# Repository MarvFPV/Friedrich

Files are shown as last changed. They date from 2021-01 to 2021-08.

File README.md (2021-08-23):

# Friedrich
50% 3D printed keyboard designed to be printable on regular sized 3d printers.

This place is designed to be 3d printed with a regular FDM printer, beware of that when ordering it from any other material. 

To make the case printable on regular machines, i had to cut it in half. To fuse those halves together you can either use super glue or melt them together by running a (clean) soldering iron tip through the seam (my preferred way). Make sure to re-tin your soldering iron afterwards tho as this process may damage your tip.

## Required components for handwires
* 52 MX style switches
* 2 2u MX platemount stabs
* 1 6.25u MX platemount stab
* 52 Diodes
* a Promicro
* one of ai03's [unified daughterboards](https://github.com/ai03-2725/Unified-Daughterboard)
* a few cables to wire up the matrix
* 4 m3x6mm screws
* 6 m3x8mm countersunk screws

I personally tend to remove the microUSB connector from the Promicro and solder it directly to a unified daughterboard, that's also why the Promicro cutout may not fit with the USB connector still on the PCB. (I should really write up some documentation on that ^^)

## PCB version
The PCB is not yet compatible with the switch plate in the repo, some cutting / melting away will have to be done to get it to fit with PCBmount stabs. Or just annoy me to add it ^^

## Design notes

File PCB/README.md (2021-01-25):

# Friedrich PCB

[][cc-by-nc-sa]

### Atmega32u4 based PCB for the Friedrich50 keyboard



---

[LCSC BOM](FriedrichPCB.csv)

[JLC CPL](FriedrichPCB_cpl_jlc.csv)

[JST connector for USB](https://www.digikey.de/product-detail/en/jst-sales-america-inc/SM04B-SRSS-TB-LF-SN/455-1804-1-ND/926875)

---




This work is licensed under a
[Creative Commons Attribution-NonCommercial-ShareAlike 4.0 International License][cc-by-nc-sa].

[][cc-by-nc-sa]

[cc-by-nc-sa]: http://creativecommons.org/licenses/by-nc-sa/4.0/
[cc-by-nc-sa-image]: https://licensebuttons.net/l/by-nc-sa/4.0/88x31.png
[cc-by-nc-sa-shield]: https://img.shields.io/badge/License-CC%20BY--NC--SA%204.0-lightgrey.svg

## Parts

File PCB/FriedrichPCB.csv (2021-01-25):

Comment | Designator | Footprint | LCSC
10uF | C1 | Capacitor_SMD:C_0805_2012Metric | C91245
0.1uF | C2,C3,C4,C5 | Capacitor_SMD:C_0805_2012Metric | C49678
1uF | C7 | Capacitor_SMD:C_0805_2012Metric | C28323
22pF | C8,C9 | Capacitor_SMD:C_0805_2012Metric | C1804
D_Small | D1,D2,D3,D4,D5,D6,D7,D8,D9,D10,D11,D12,D13,D14,D15,D16,D17,D18,D19,D20,D21,D22,D23,D24,D25,D27,D28,D29,D30,D31,D32,D33,D34,D35,D36,D38,D40,D41,D42,D43,D44,D45,D46,D47,D48,D49,D51,D53,D54,D58,D62,D63 | Diode_SMD:D_SOD-123 | C81598
Polyfuse_Small | F1 | Fuse:Fuse_1206_3216Metric | C163133
MX-NoLED | MX1,MX2,MX3,MX4,MX5,MX6,MX7,MX8,MX9,MX10,MX11,MX12,MX13,MX15,MX16,MX17,MX18,MX19,MX20,MX21,MX22,MX23,MX24,MX28,MX29,MX30,MX31,MX32,MX33,MX34,MX35,MX36,MX41,MX42,MX43,MX44,MX45,MX46,MX47,MX48,MX49,MX53,MX63 | MX_Only:MXOnly-1U-NoLED
MX-NoLED | MX14,MX25 | MX_Only:MXOnly-1.5U-NoLED
MX-NoLED | MX27,MX51 | MX_Only:MXOnly-1.75U-NoLED
MX-NoLED | MX38 | MX_Only:MXOnly-2.25U-NoLED
MX-NoLED | MX40 | MX_Only:MXOnly-2.25U-ReversedStabilizers-NoLED
MX-NoLED | MX54,MX62 | MX_Only:MXOnly-1.25U-NoLED
MX-NoLED | MX58 | MX_Only:MXOnly-6.25U-ReversedStabilizers-NoLED
22 | R1,R2 | Resistor_SMD:R_0805_2012Metric | C17561
10k | R3,R5 | Resistor_SMD:R_0805_2012Metric | C17414
SW_Push | RESET | Button_Switch_SMD:SW_SPST_TL3342 | C318884
ATmega32U4-AU | U1 | Package_QFP:TQFP-44_10x10mm_P0.8mm | C44854
SRV05-4 | U2 | Package_TO_SOT_SMD:SOT-23-6 | C85364
Conn_01x04 | USB1 | Connector_JST:JST_SH_SM04B-SRSS-TB_1x04-1MP_P1.00mm_Horizontal
Crystal_GND24_Small | X1 | Crystal:Crystal_SMD_3225-4Pin_3.2x2.5mm | C13738

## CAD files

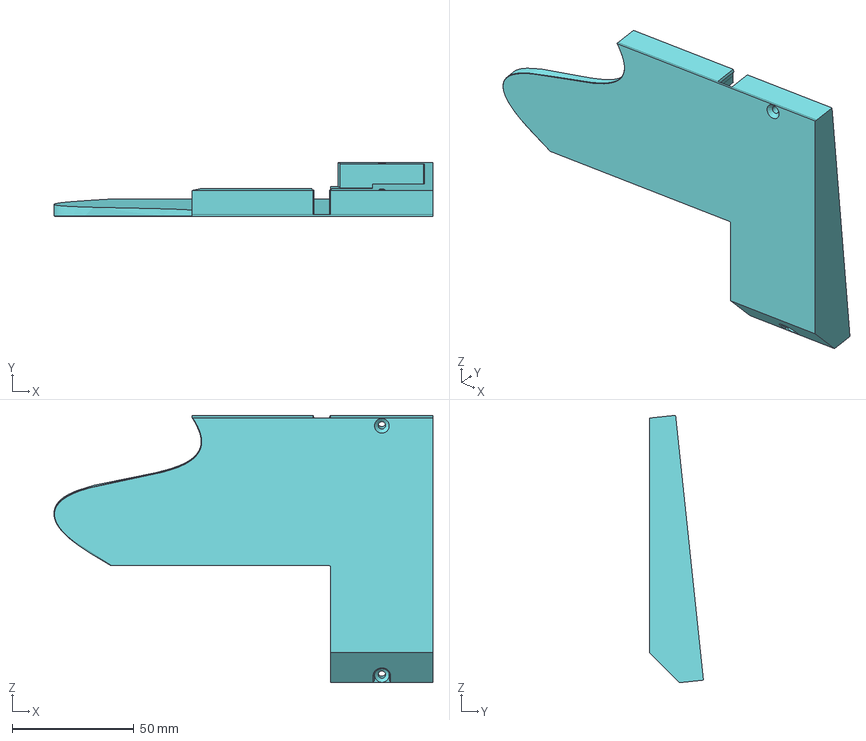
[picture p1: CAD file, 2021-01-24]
STEP/BottomRight.step
155.3 x 22.1 x 109.6 mm

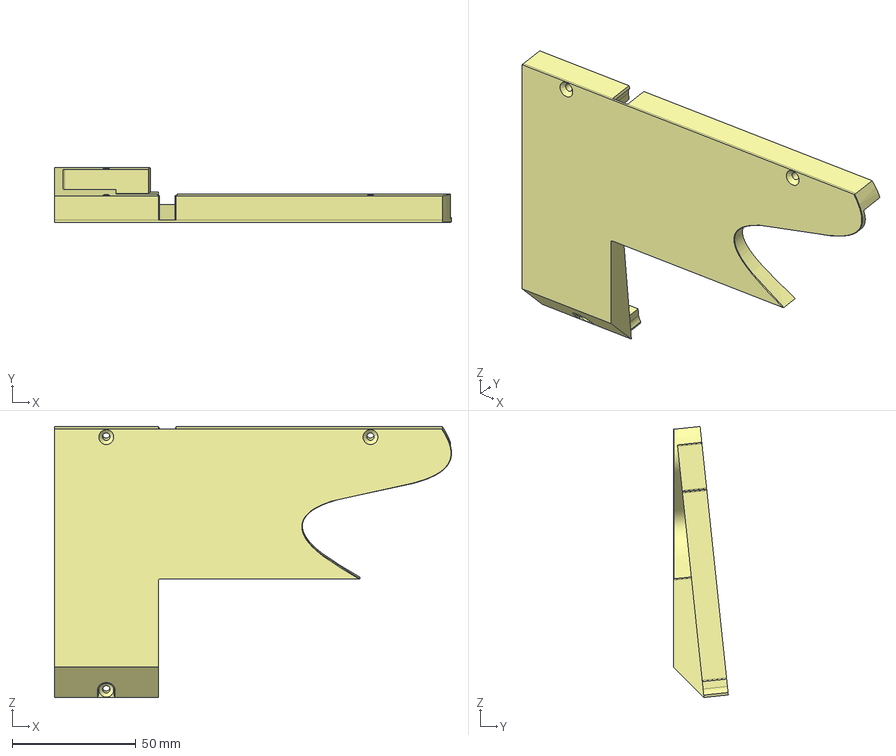
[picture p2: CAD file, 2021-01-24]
STEP/BottomLeft.step
160.5 x 22.1 x 109.6 mm

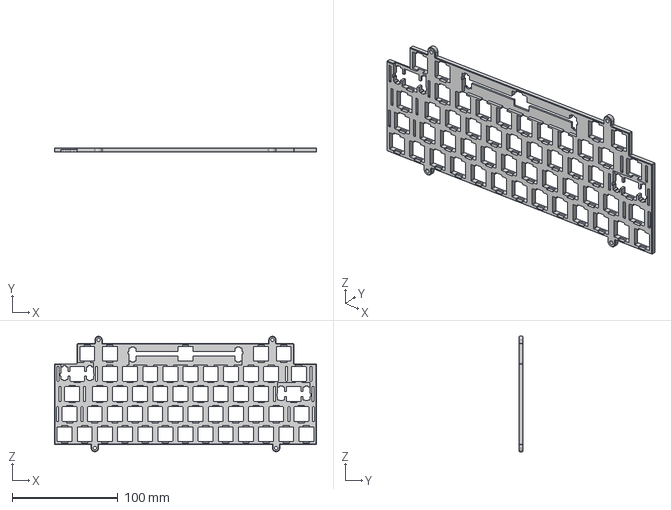
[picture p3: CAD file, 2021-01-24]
STEP/Plate.step
247.7 x 4.00 x 109.2 mm

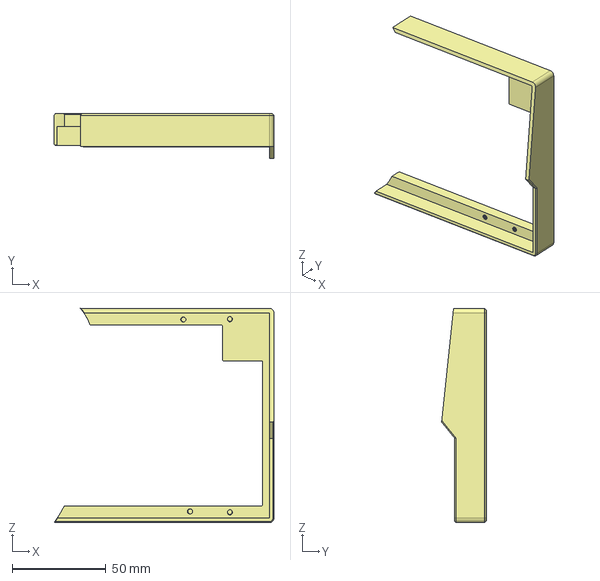
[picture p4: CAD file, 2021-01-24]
STEP/TopRight.step
117.2 x 23.9 x 114.2 mm

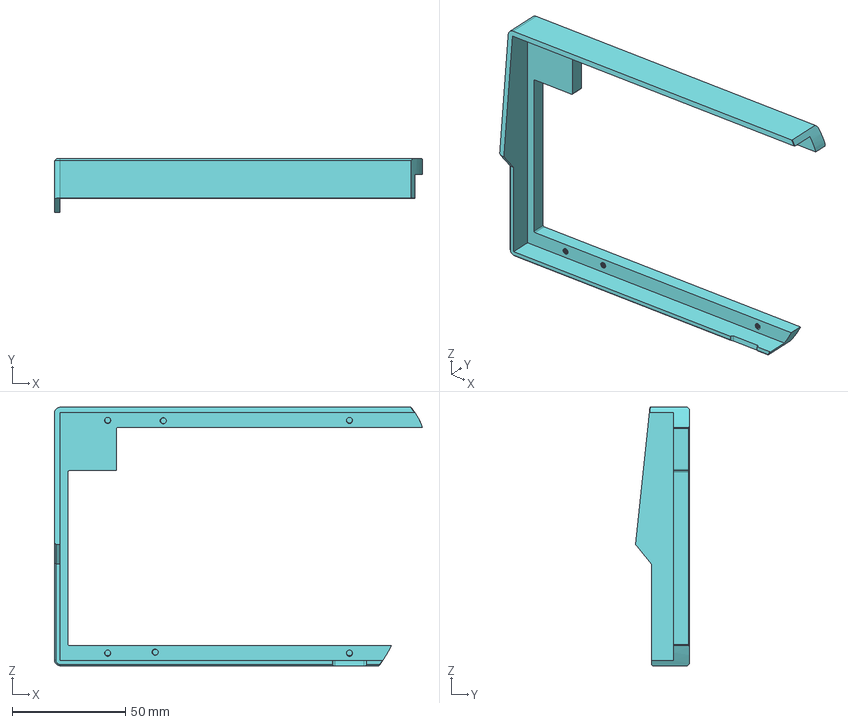
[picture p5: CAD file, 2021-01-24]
STEP/TopLeft.step
162.6 x 23.9 x 114.3 mm

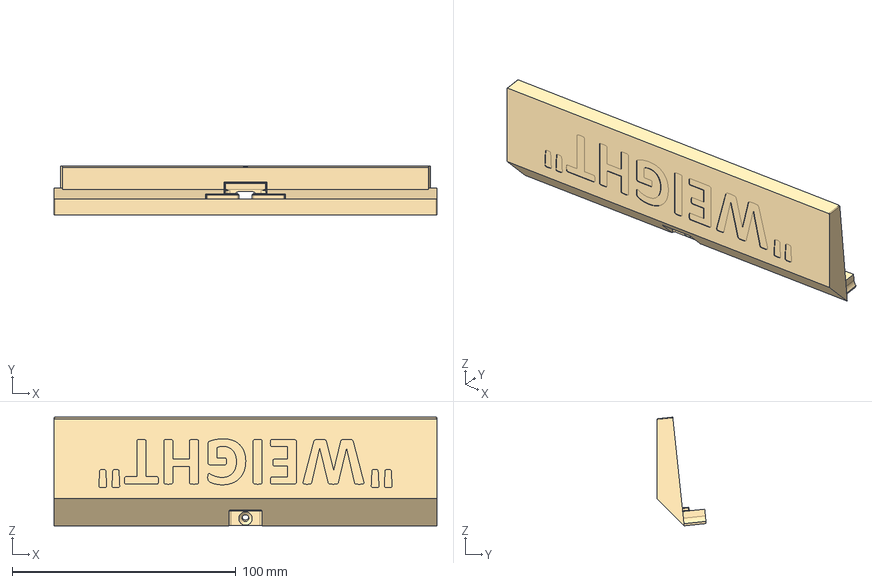
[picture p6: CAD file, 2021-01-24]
STEP/Weight.step
171.1 x 22.1 x 48.6 mm

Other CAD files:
STL/BottomLeft.stl
STL/BottomRight.stl
STL/Plate.stl
STL/TopLeft.stl
STL/TopRight.stl
STL/Weight.stl

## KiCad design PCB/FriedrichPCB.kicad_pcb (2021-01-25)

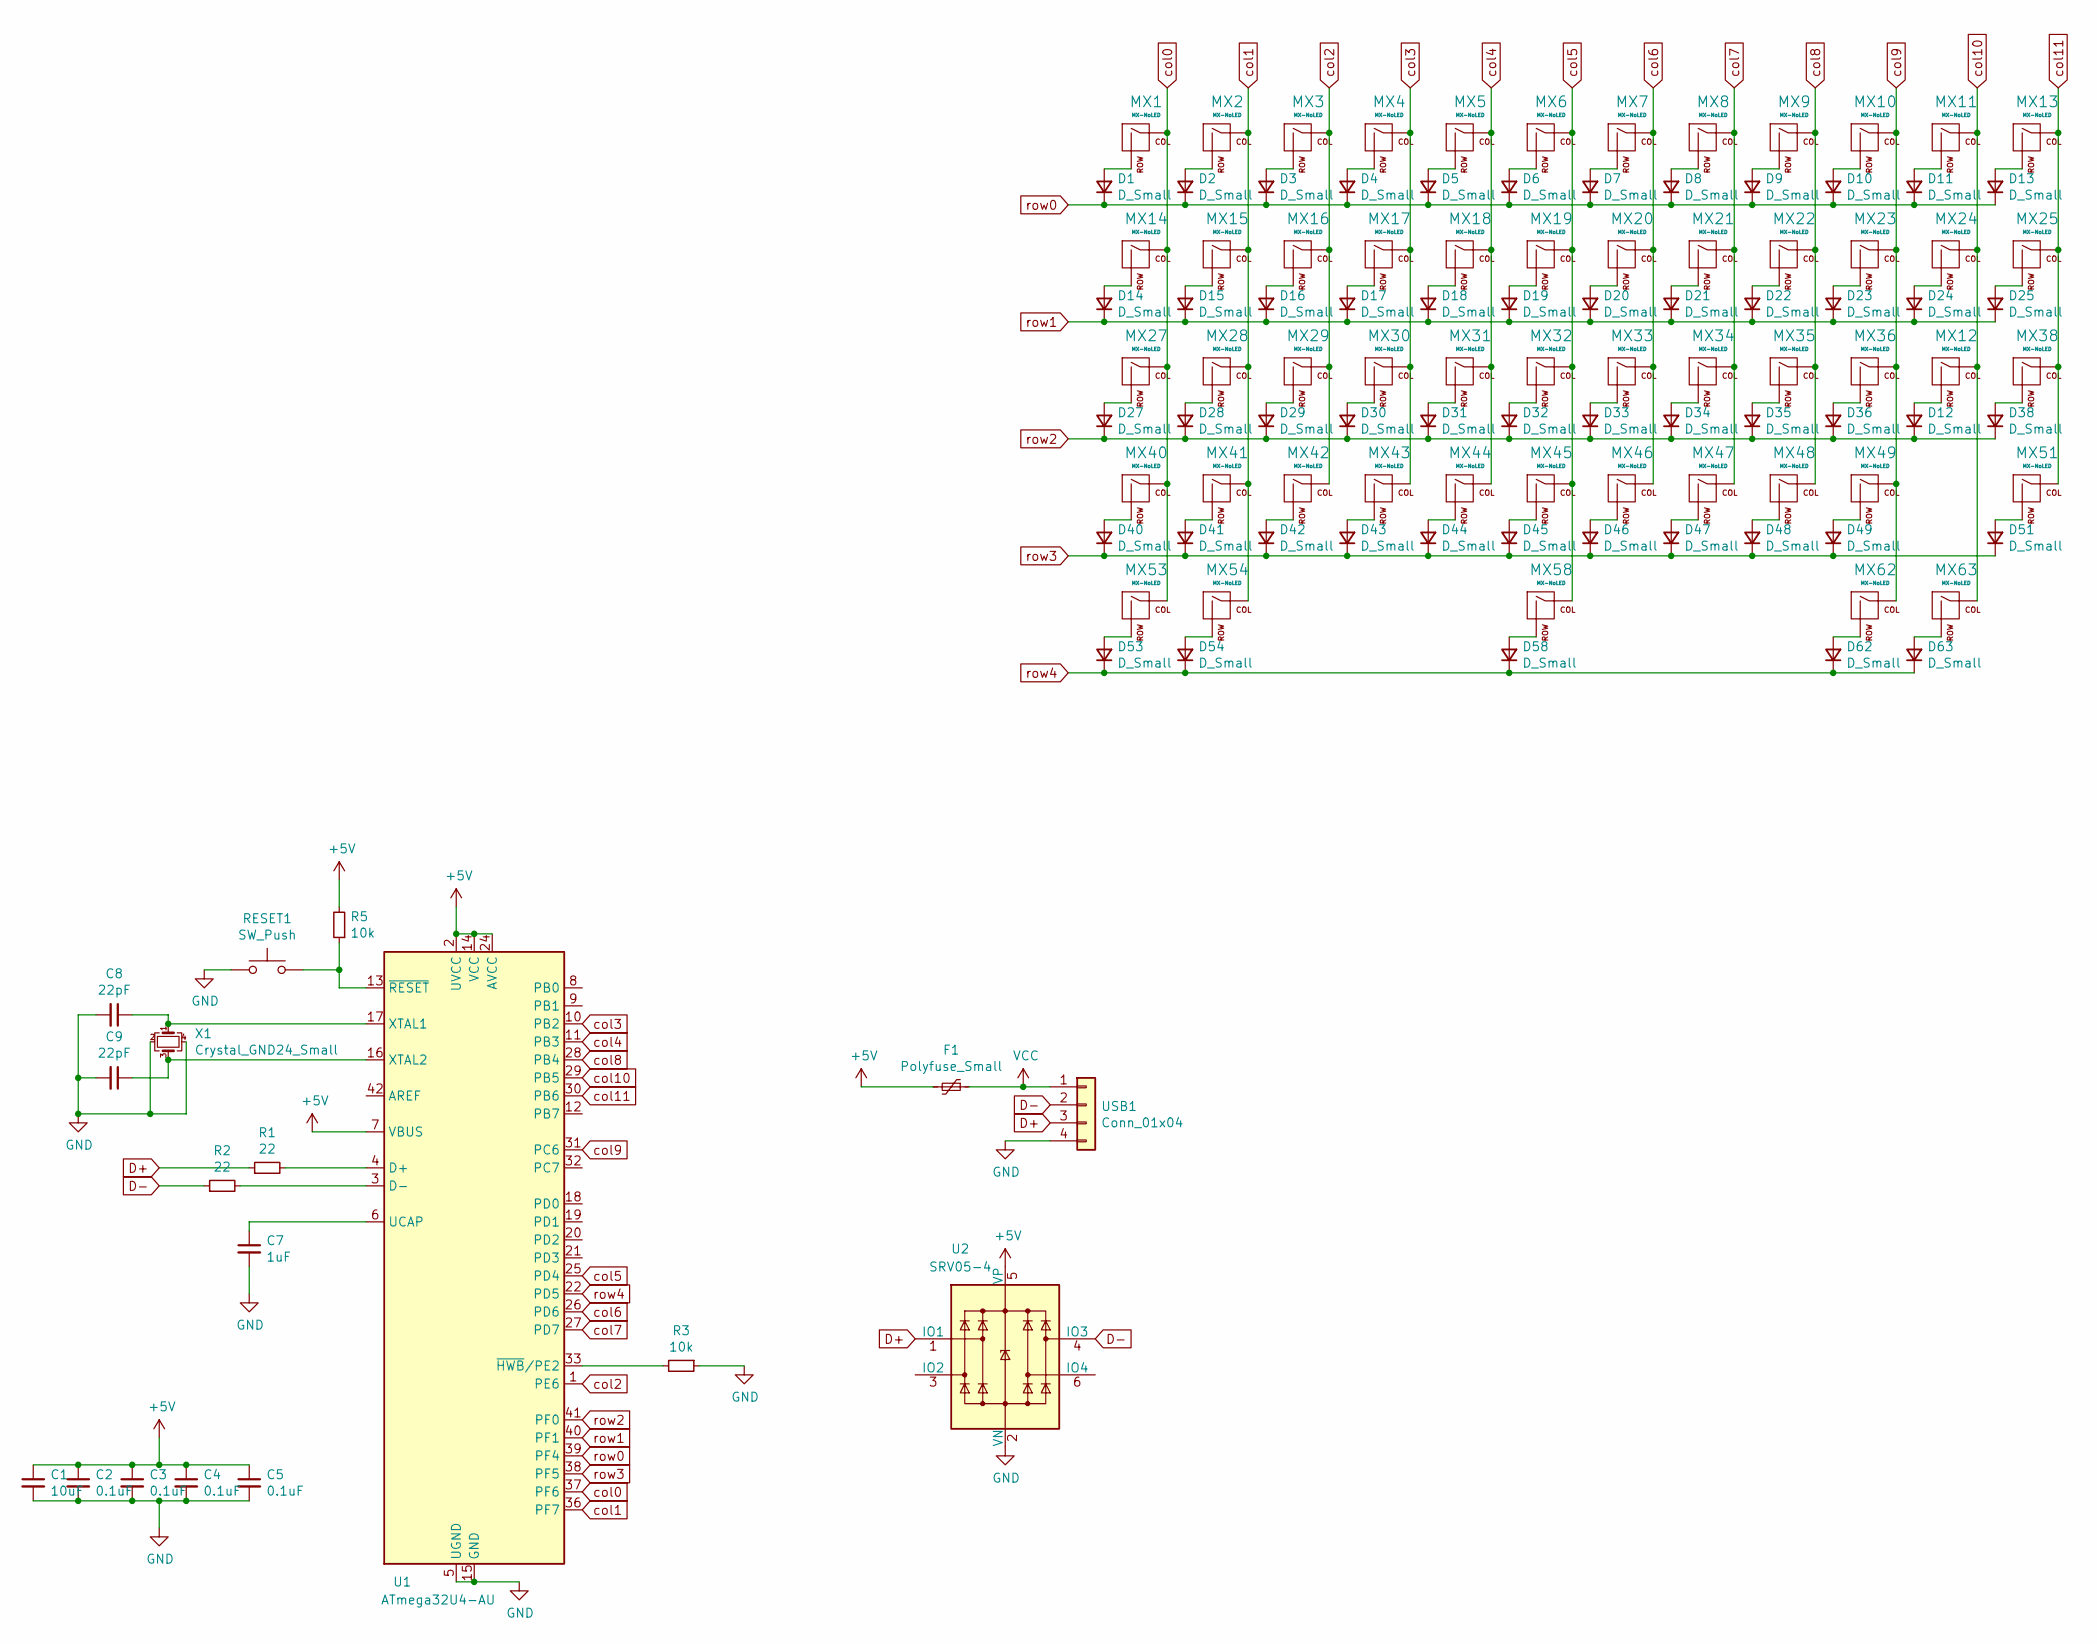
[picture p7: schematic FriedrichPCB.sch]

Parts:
C1: 10uF; C_0805_2012Metric; LCSC C91245
C2, C3, C4, C5: 0.1uF; C_0805_2012Metric; LCSC C49678
C7: 1uF; C_0805_2012Metric; LCSC C28323
C8, C9: 22pF; C_0805_2012Metric; LCSC C1804
D1, D2, D3, D4, D5, D6, D7, D8, D9, D10, D11, D12, D13, D14, D15, D16, D17, D18, D19, D20, D21, D22, D23, D24, D25, D27, D28, D29, D30, D31, D32, D33, D34, D35, D36, D38, D40, D41, D42, D43, D44, D45, D46, D47, D48, D49, D51, D53, D54, D58, D62, D63: D_Small; D_SOD-123; LCSC C81598
F1: Polyfuse_Small; Fuse_1206_3216Metric; LCSC C163133
MX1, MX2, MX3, MX4, MX5, MX6, MX7, MX8, MX9, MX10, MX11, MX12, MX13, MX15, MX16, MX17, MX18, MX19, MX20, MX21, MX22, MX23, MX24, MX28, MX29, MX30, MX31, MX32, MX33, MX34, MX35, MX36, MX41, MX42, MX43, MX44, MX45, MX46, MX47, MX48, MX49, MX53, MX63: MX-NoLED; MXOnly-1U-NoLED
MX14, MX25: MX-NoLED; MXOnly-1.5U-NoLED
MX27, MX51: MX-NoLED; MXOnly-1.75U-NoLED
MX38: MX-NoLED; MXOnly-2.25U-NoLED
MX40: MX-NoLED; MXOnly-2.25U-ReversedStabilizers-NoLED
MX54, MX62: MX-NoLED; MXOnly-1.25U-NoLED
MX58: MX-NoLED; MXOnly-6.25U-ReversedStabilizers-NoLED
R1, R2: 22; R_0805_2012Metric; LCSC C17561
R3, R5: 10k; R_0805_2012Metric; LCSC C17414
RESET1: SW_Push; SW_SPST_TL3342; LCSC C318884
U1: ATmega32U4-AU; TQFP-44_10x10mm_P0.8mm; LCSC C44854
U2: SRV05-4; SOT-23-6; LCSC C85364
USB1: Conn_01x04; JST_SH_SM04B-SRSS-TB_1x04-1MP_P1.00mm_Horizontal
X1: Crystal_GND24_Small; Crystal_SMD_3225-4Pin_3.2x2.5mm; LCSC C13738

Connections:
+5V: C1.1, C2.1, C3.1, C4.1, C5.1, F1.2, R5.2, U1.2 (UVCC), U1.7 (VBUS), U1.14 (VCC), U1.24 (AVCC), U1.34 (VCC), U1.44 (AVCC), U2.5 (VP)
D+: R1.1, U2.1 (IO1), USB1.3
D-: R2.1, U2.4 (IO3), USB1.2
GND: C1.2, C2.2, C3.2, C4.2, C5.2, C7.2, C8.2, C9.2, R3.1, RESET1.1, U1.5 (UGND), U1.15 (GND), U1.23 (GND), U1.35 (GND), U1.43 (GND), U2.2 (VN), USB1.4, X1.2, X1.4; also elsewhere on the board
unnamed: C7.1, U1.6 (UCAP)
unnamed: C8.1, U1.17 (XTAL1), X1.1
unnamed: C9.1, U1.16 (XTAL2), X1.3
unnamed: D1.2 (A), MX1.2 (ROW)
unnamed: D2.2 (A), MX2.2 (ROW)
unnamed: D3.2 (A), MX3.2 (ROW)
unnamed: D4.2 (A), MX4.2 (ROW)
unnamed: D5.2 (A), MX5.2 (ROW)
unnamed: D6.2 (A), MX6.2 (ROW)
unnamed: D7.2 (A), MX7.2 (ROW)
unnamed: D8.2 (A), MX8.2 (ROW)
unnamed: D9.2 (A), MX9.2 (ROW)
unnamed: D10.2 (A), MX10.2 (ROW)
unnamed: D11.2 (A), MX11.2 (ROW)
unnamed: D12.2 (A), MX12.2 (ROW)
unnamed: D13.2 (A), MX13.2 (ROW)
unnamed: D14.2 (A), MX14.2 (ROW)
unnamed: D15.2 (A), MX15.2 (ROW)
unnamed: D16.2 (A), MX16.2 (ROW)
unnamed: D17.2 (A), MX17.2 (ROW)
unnamed: D18.2 (A), MX18.2 (ROW)
unnamed: D19.2 (A), MX19.2 (ROW)
unnamed: D20.2 (A), MX20.2 (ROW)
unnamed: D21.2 (A), MX21.2 (ROW)
unnamed: D22.2 (A), MX22.2 (ROW)
unnamed: D23.2 (A), MX23.2 (ROW)
unnamed: D24.2 (A), MX24.2 (ROW)
unnamed: D25.2 (A), MX25.2 (ROW)
unnamed: D27.2 (A), MX27.2 (ROW)
unnamed: D28.2 (A), MX28.2 (ROW)
unnamed: D29.2 (A), MX29.2 (ROW)
unnamed: D30.2 (A), MX30.2 (ROW)
unnamed: D31.2 (A), MX31.2 (ROW)
unnamed: D32.2 (A), MX32.2 (ROW)
unnamed: D33.2 (A), MX33.2 (ROW)
unnamed: D34.2 (A), MX34.2 (ROW)
unnamed: D35.2 (A), MX35.2 (ROW)
unnamed: D36.2 (A), MX36.2 (ROW)
unnamed: D38.2 (A), MX38.2 (ROW)
unnamed: D40.2 (A), MX40.2 (ROW)
unnamed: D41.2 (A), MX41.2 (ROW)
unnamed: D42.2 (A), MX42.2 (ROW)
unnamed: D43.2 (A), MX43.2 (ROW)
unnamed: D44.2 (A), MX44.2 (ROW)
unnamed: D45.2 (A), MX45.2 (ROW)
unnamed: D46.2 (A), MX46.2 (ROW)
unnamed: D47.2 (A), MX47.2 (ROW)
unnamed: D48.2 (A), MX48.2 (ROW)
unnamed: D49.2 (A), MX49.2 (ROW)
unnamed: D51.2 (A), MX51.2 (ROW)
unnamed: D53.2 (A), MX53.2 (ROW)
unnamed: D54.2 (A), MX54.2 (ROW)
unnamed: D58.2 (A), MX58.2 (ROW)
unnamed: D62.2 (A), MX62.2 (ROW)
unnamed: D63.2 (A), MX63.2 (ROW)
unnamed: R1.2, U1.4 (D+)
unnamed: R2.2, U1.3 (D-)
unnamed: R3.2, U1.33 (~HWB~/PE2)
unnamed 62: R5.1, RESET1.2, U1.13 (~RESET); also elsewhere on the board
VCC: F1.1, USB1.1
col0: MX1.1 (COL), MX14.1 (COL), MX27.1 (COL), MX40.1 (COL), MX53.1 (COL), U1.37 (PF6)
col1: MX2.1 (COL), MX15.1 (COL), MX28.1 (COL), MX41.1 (COL), MX54.1 (COL), U1.36 (PF7)
col2: MX3.1 (COL), MX16.1 (COL), MX29.1 (COL), MX42.1 (COL), U1.1 (PE6)
col3: MX4.1 (COL), MX17.1 (COL), MX30.1 (COL), MX43.1 (COL), U1.10 (PB2)
col4: MX5.1 (COL), MX18.1 (COL), MX31.1 (COL), MX44.1 (COL), U1.11 (PB3)
col5: MX6.1 (COL), MX19.1 (COL), MX32.1 (COL), MX45.1 (COL), MX58.1 (COL), U1.25 (PD4)
col6: MX7.1 (COL), MX20.1 (COL), MX33.1 (COL), MX46.1 (COL), U1.26 (PD6)
col7: MX8.1 (COL), MX21.1 (COL), MX34.1 (COL), MX47.1 (COL), U1.27 (PD7)
col8: MX9.1 (COL), MX22.1 (COL), MX35.1 (COL), MX48.1 (COL), U1.28 (PB4)
col9: MX10.1 (COL), MX23.1 (COL), MX36.1 (COL), MX49.1 (COL), MX62.1 (COL), U1.31 (PC6)
col10: MX11.1 (COL), MX12.1 (COL), MX24.1 (COL), MX63.1 (COL), U1.29 (PB5)
col11: MX13.1 (COL), MX25.1 (COL), MX38.1 (COL), MX51.1 (COL), U1.30 (PB6)
row0: D1.1 (K), D2.1 (K), D3.1 (K), D4.1 (K), D5.1 (K), D6.1 (K), D7.1 (K), D8.1 (K), D9.1 (K), D10.1 (K), D11.1 (K), D13.1 (K), U1.39 (PF4)
row1: D14.1 (K), D15.1 (K), D16.1 (K), D17.1 (K), D18.1 (K), D19.1 (K), D20.1 (K), D21.1 (K), D22.1 (K), D23.1 (K), D24.1 (K), D25.1 (K), U1.40 (PF1)
row2: D12.1 (K), D27.1 (K), D28.1 (K), D29.1 (K), D30.1 (K), D31.1 (K), D32.1 (K), D33.1 (K), D34.1 (K), D35.1 (K), D36.1 (K), D38.1 (K), U1.41 (PF0)
row3: D40.1 (K), D41.1 (K), D42.1 (K), D43.1 (K), D44.1 (K), D45.1 (K), D46.1 (K), D47.1 (K), D48.1 (K), D49.1 (K), D51.1 (K), U1.38 (PF5)
row4: D53.1 (K), D54.1 (K), D58.1 (K), D62.1 (K), D63.1 (K), U1.22 (PD5)

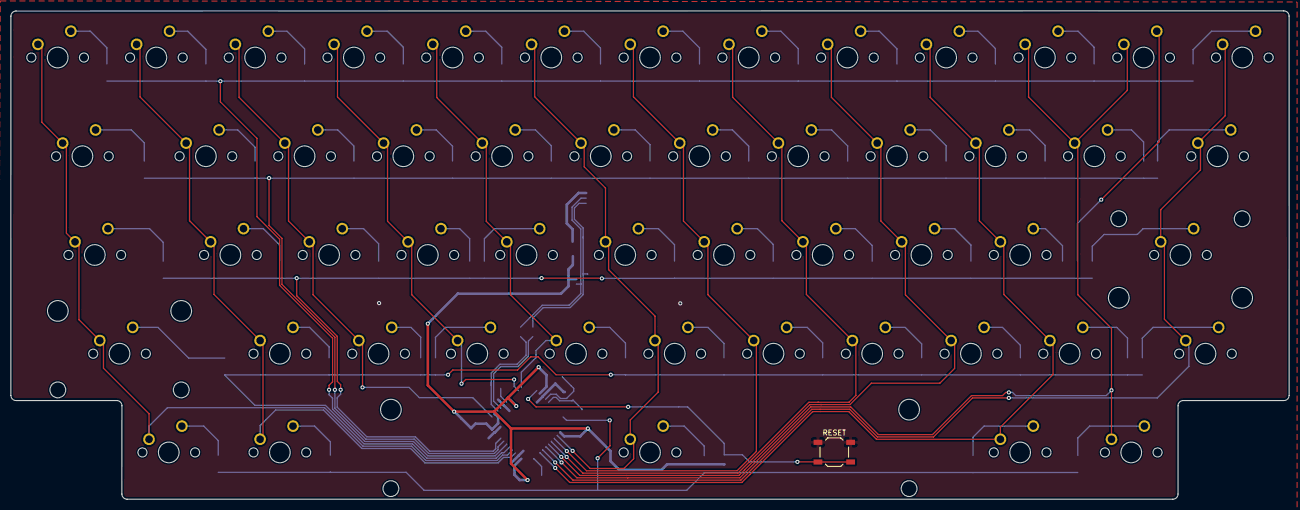
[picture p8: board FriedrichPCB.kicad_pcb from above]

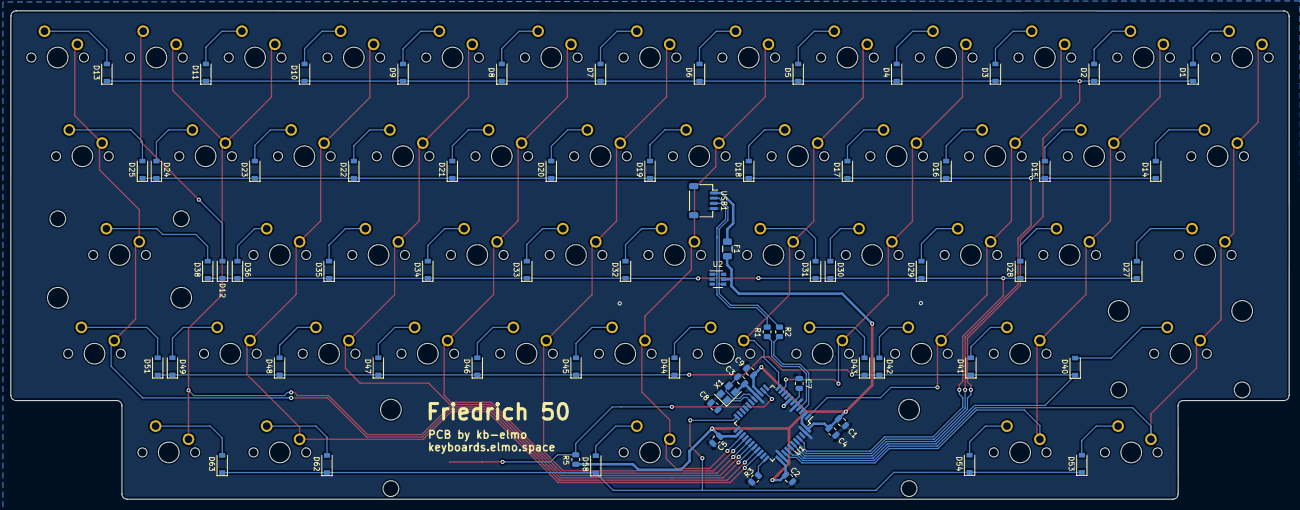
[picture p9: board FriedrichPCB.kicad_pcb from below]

Board: 2 copper layers, 246.7 x 94.2 mm, 122 parts (69 on the bottom side), 81 nets.

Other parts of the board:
RESET: SW_Push; SW_SPST_TL3342

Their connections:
GND: RESET.1; also elsewhere on the board
unnamed 62: RESET.2; also elsewhere on the board

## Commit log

2021-01-24 Added 3D files
    [BottomLeft.step, BottomLeft.stl, BottomRight.step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]
2021-01-25 add PCB
    [FriedrichPCB-B_Cu.gbr, FriedrichPCB-B_Mask.gbr, FriedrichPCB-B_Paste.gbr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]

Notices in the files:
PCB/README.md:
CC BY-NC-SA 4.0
